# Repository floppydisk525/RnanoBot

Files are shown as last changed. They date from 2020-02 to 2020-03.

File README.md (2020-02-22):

# RnanoBot
This github repository contains the KiCAD files and supporting documents for an Arduino Nano shield containing a TB6612 motor driver chip and LSM9DS1TR 9DOF IMU.  

The TB6612 circuit was influenced from https://github.com/floppydisk525/BoxBotCtrlBrd, which in turn was influenced from https://github.com/BoxBots/control-board.  

The LSM9DS1TR chip was influenced from sparkfun projects such as https://www.sparkfun.com/products/13944 and others.  

The repository name RnanoBot comes from "aRduino NANO roBOT" motor shield with TB6612 &amp; LSM9DS1TR.  

### Datasheets  
Datasheets are in the https://github.com/floppydisk525/RnanoBot/tree/master/board/datasheets folder.  
# Typical Application Notes  
Here are typical application images for key componets.  
## TB6612  
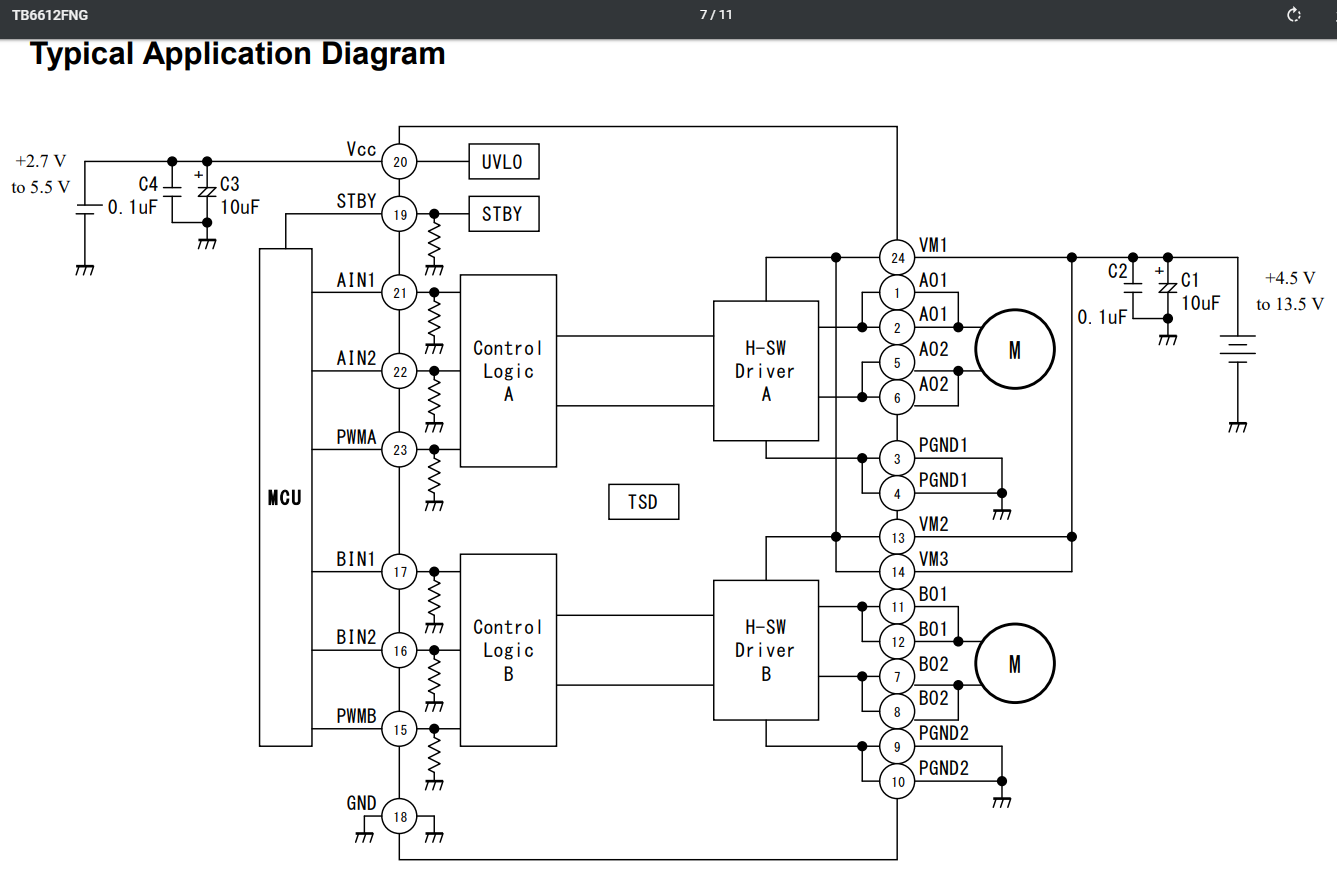
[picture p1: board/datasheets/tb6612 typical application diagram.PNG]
  
## LSM9DS1TR  
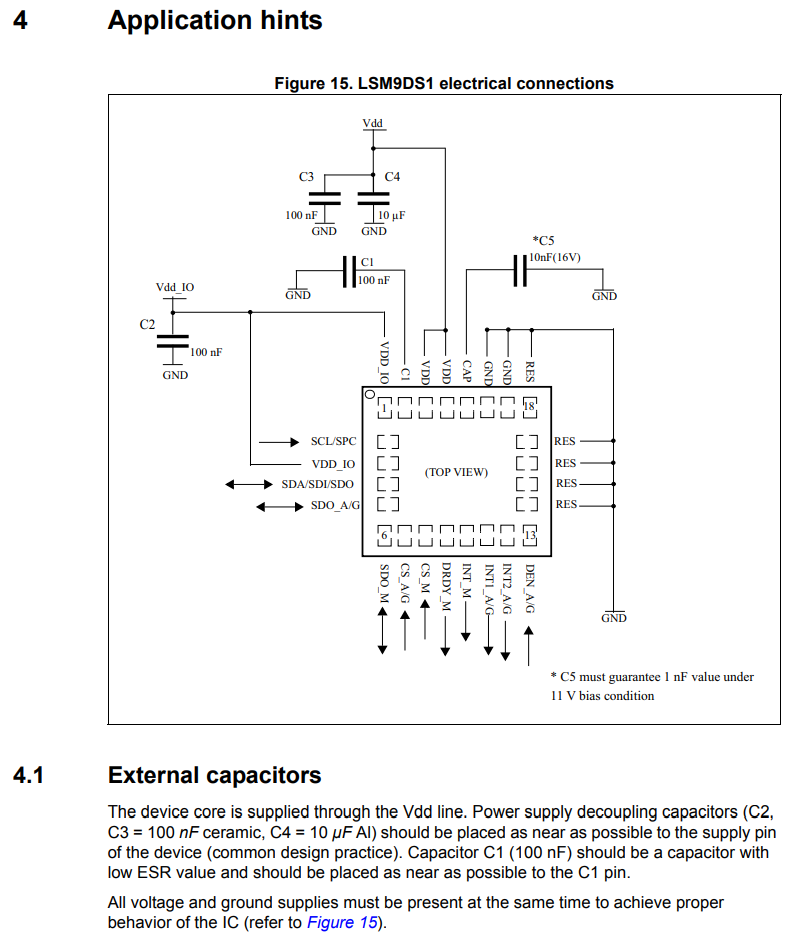
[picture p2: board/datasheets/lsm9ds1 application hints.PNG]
  
The following cut/paste is from:  https://learn.sparkfun.com/tutorials/lsm9ds1-breakout-hookup-guide:  
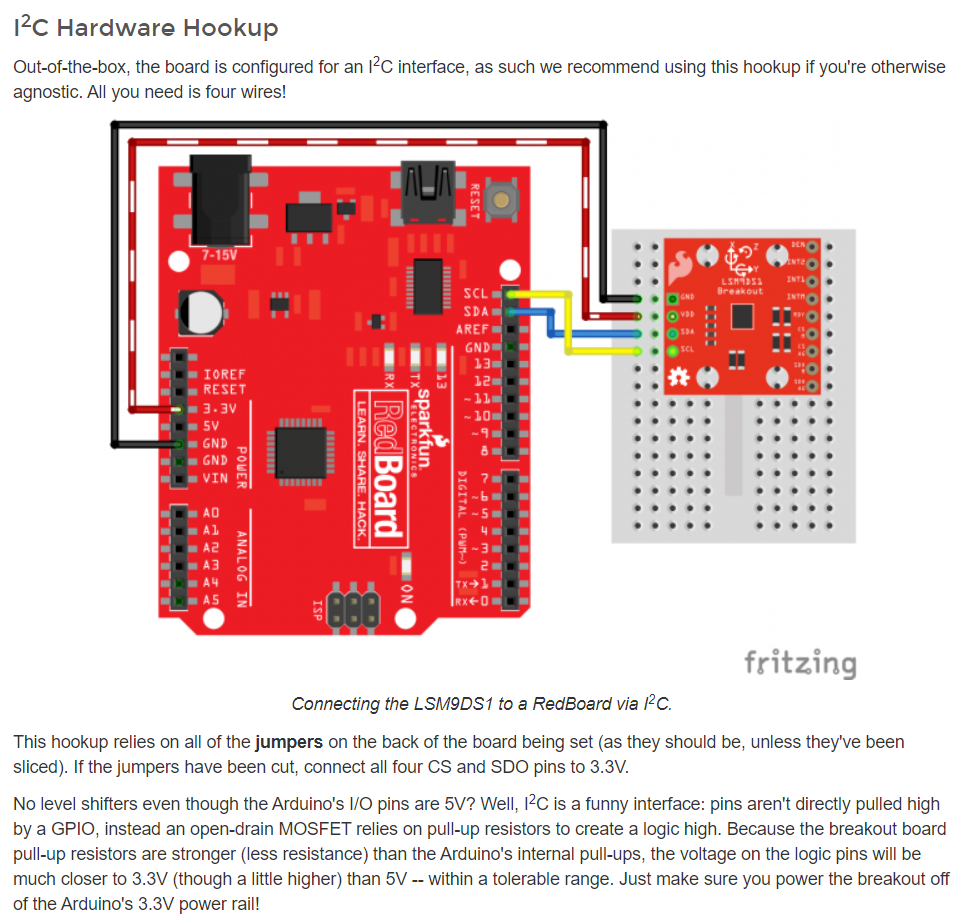
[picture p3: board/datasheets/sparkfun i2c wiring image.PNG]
  

## Arduino NANO Pinout  
I really like this Arduino NANO pinout from Components 101 https://components101.com/microcontrollers/arduino-nano:  
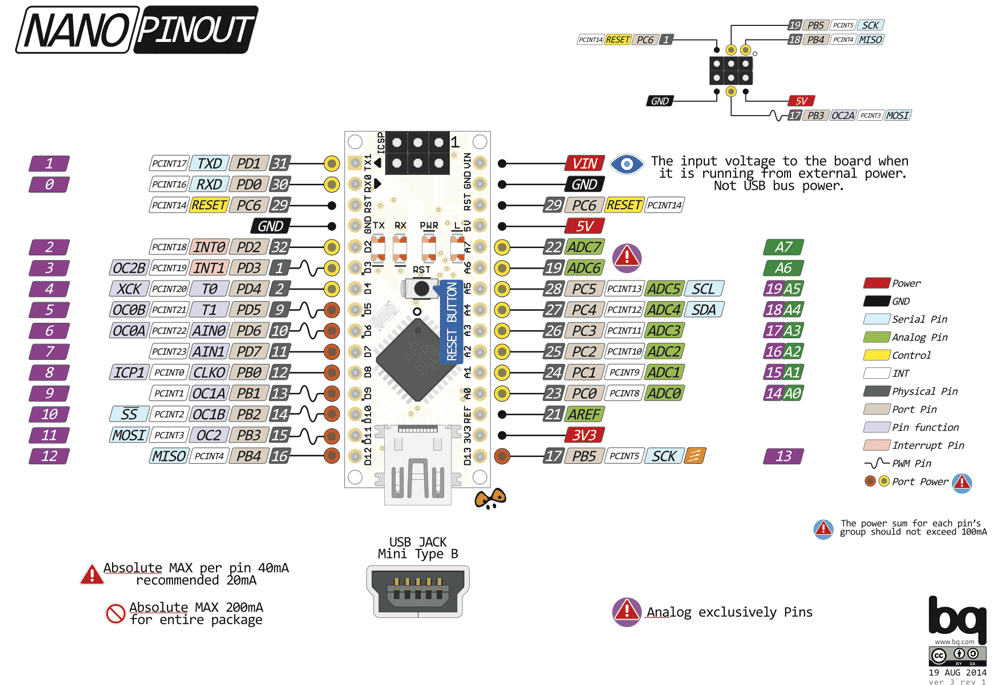
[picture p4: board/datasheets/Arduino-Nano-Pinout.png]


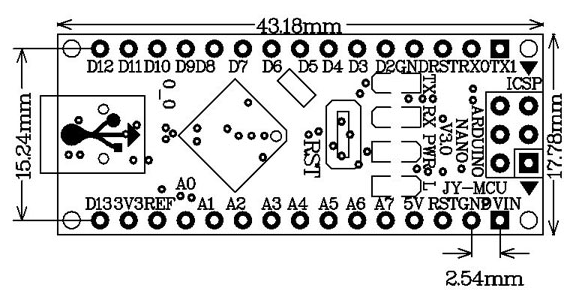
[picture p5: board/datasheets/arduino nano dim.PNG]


### References
https://learn.sparkfun.com/tutorials/lsm9ds1-breakout-hookup-guide  
https://www.sparkfun.com/products/13944  
https://cdn.sparkfun.com/assets/b/0/f/7/4/SparkFun_Motor_Driver-TB6612FNG_v11c.pdf  
https://www.digikey.com/product-detail/en/stmicroelectronics/LSM9DS1TR/497-14946-1-ND/4988079  
https://www.digikey.com/product-detail/en/toshiba-semiconductor-and-storage/TB6612FNGC8EL/TB6612FNGC8ELCT-ND/1730134  
https://components101.com/microcontrollers/arduino-nano  
https://www.youtube.com/watch?v=gGix1oYhTRs  
https://www.st.com/resource/en/datasheet/lsm9ds1.pdf  
http://cheasokchenda.blogspot.com/2018/05/you-can-click-on-link-bellow-to-get-6.html  

[tb6612]:/board/datasheets/tb6612%20typical%20application%20diagram.PNG "TB6612 Typical Application Diagram"
[lsm9ds1]:/board/datasheets/lsm9ds1%20application%20hints.PNG "LSM9DS1TR Application Hint from Datasheet"
[lsm9ds1_spark]:/board/datasheets/sparkfun%20i2c%20wiring%20image.PNG "LSM9DS1TR Spark Fun I2C Wiring example"
[ardnano]:/board/datasheets/Arduino-Nano-Pinout.png "Arduino NANO Pinout from Components 101"
[ard_dim]:/board/datasheets/arduino%20nano%20dim.PNG "Arduino Physical Dimensions"

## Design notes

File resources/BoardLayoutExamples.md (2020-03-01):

# Board Layout Ideas  

The idea is that the board will be a motor shield and accept an arduino Nano.  It is based off the [BoxBotCtrlBrd](https://github.com/floppydisk525/BoxBotCtrlBrd) project and is an improved shield with an ICU added for better control and more capabilities.  

# [BoxBotCtrlBrd](https://github.com/floppydisk525/BoxBotCtrlBrd) Project  
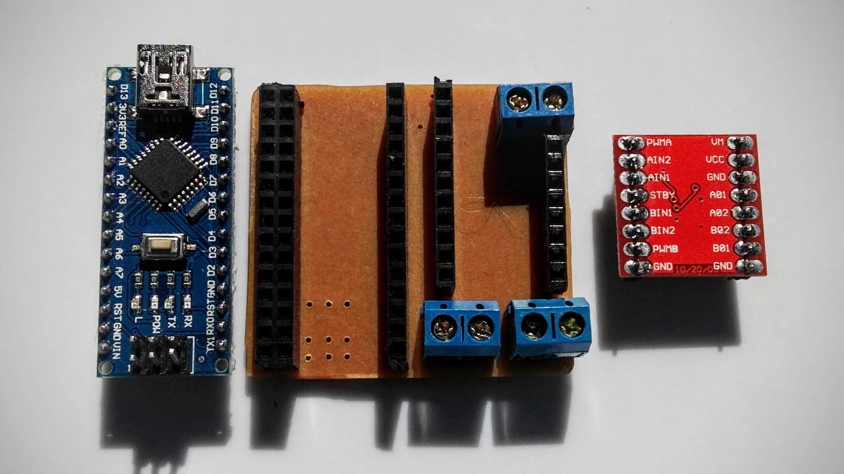
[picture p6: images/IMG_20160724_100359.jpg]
  
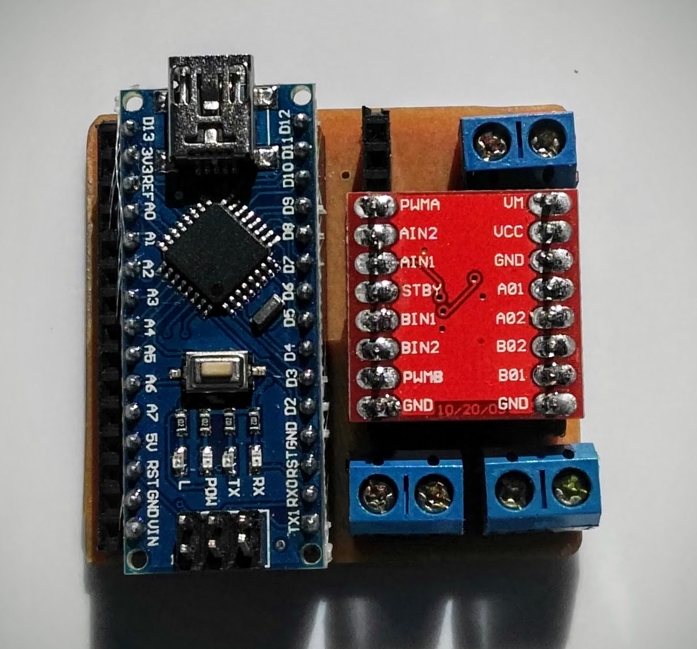
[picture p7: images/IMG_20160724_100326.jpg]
  

# [Rapidonline Example:](https://www.rapidonline.com/arduino-asx00004-mkr-485-rs485-protocol-shield-for-industrial-connections-73-4854)  
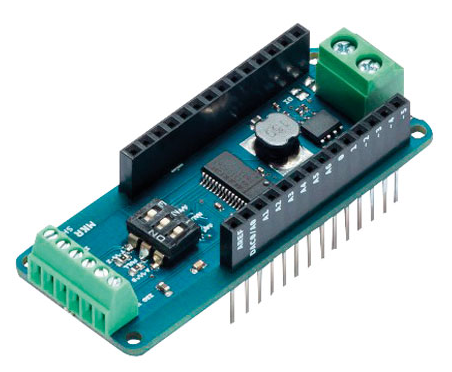
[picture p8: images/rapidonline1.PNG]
  
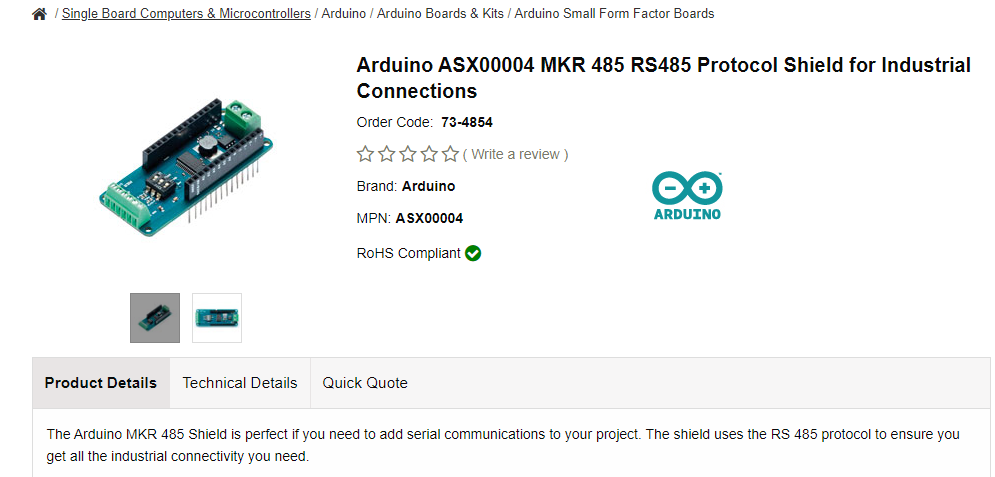
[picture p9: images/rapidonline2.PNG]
  

# [Openhardware IO Shield](https://www.openhardware.io/view/710/Arduino-Nano-NRF24L01-Shield#tabs-comments)  
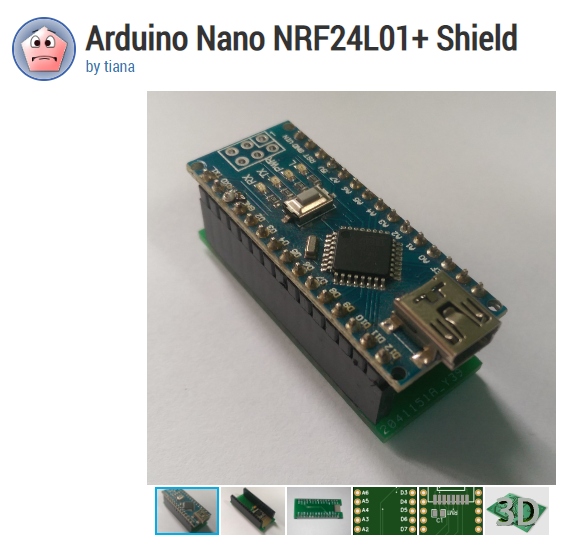
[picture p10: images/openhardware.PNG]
  

# [Freelance Nano Motor Shield Example](https://www.freelancer.com/u/vortexe9000/portfolio/Arduino-Nano-v30-shield-for-small-DC-motors-3527320)  
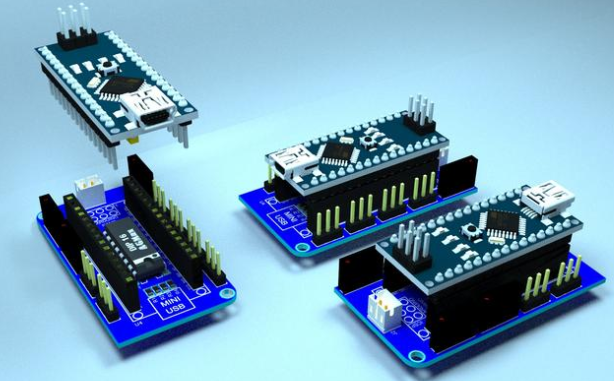
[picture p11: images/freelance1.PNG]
  
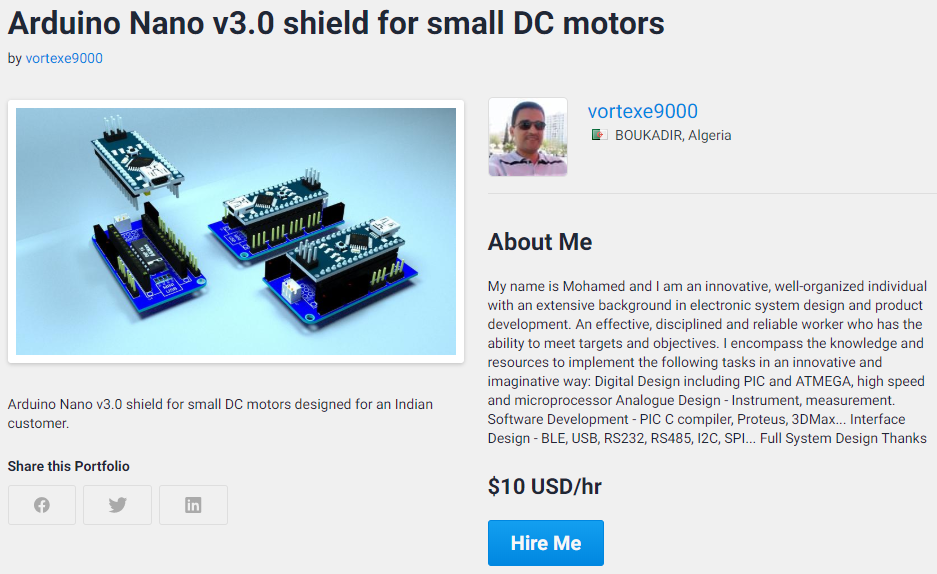
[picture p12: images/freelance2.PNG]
  

# [CE Nano Shield Example](https://shop.controleverything.com/products/arduino-nano-i2c-shield)  
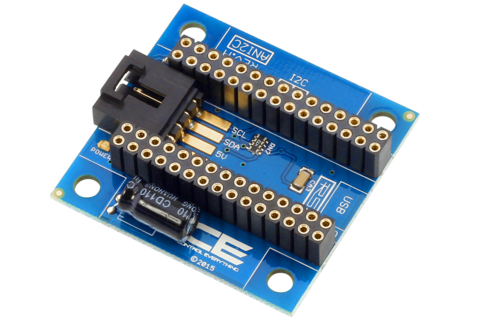
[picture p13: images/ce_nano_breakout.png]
  

# [Gravitech Nano Motor Shield - Nice!](http://www.gravitech.us/2mwfecoadfor.html)  
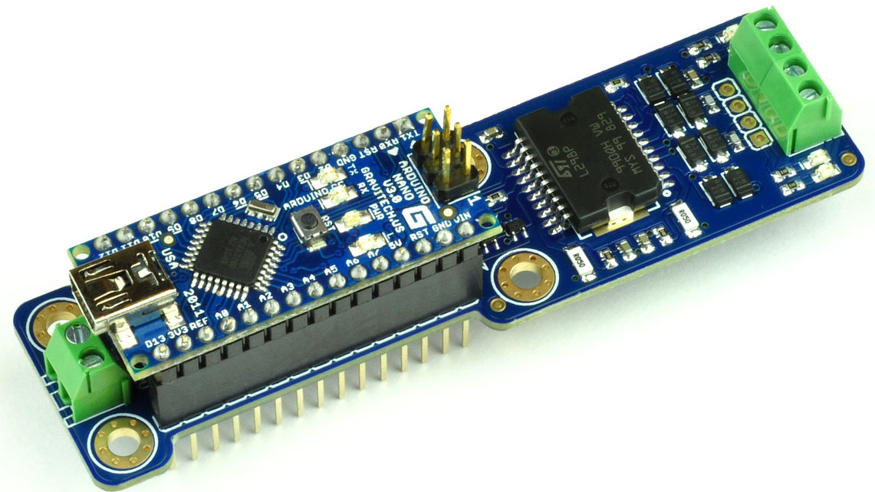
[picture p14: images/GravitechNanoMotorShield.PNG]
 

# RnanoBot - Phoenix Contact Connectors TOO TALL!  
The beauty of KiCAD 3d - look at how tall those phoenix contact connectors are in the 3d view!  TOO TALL!  Going away from them and to basic .1" headers with [CRHO](http://dangerousprototypes.com/blog/2017/06/22/dirty-cables-whats-in-that-pile/) connectors.  Easy, cheap, compact, doable!
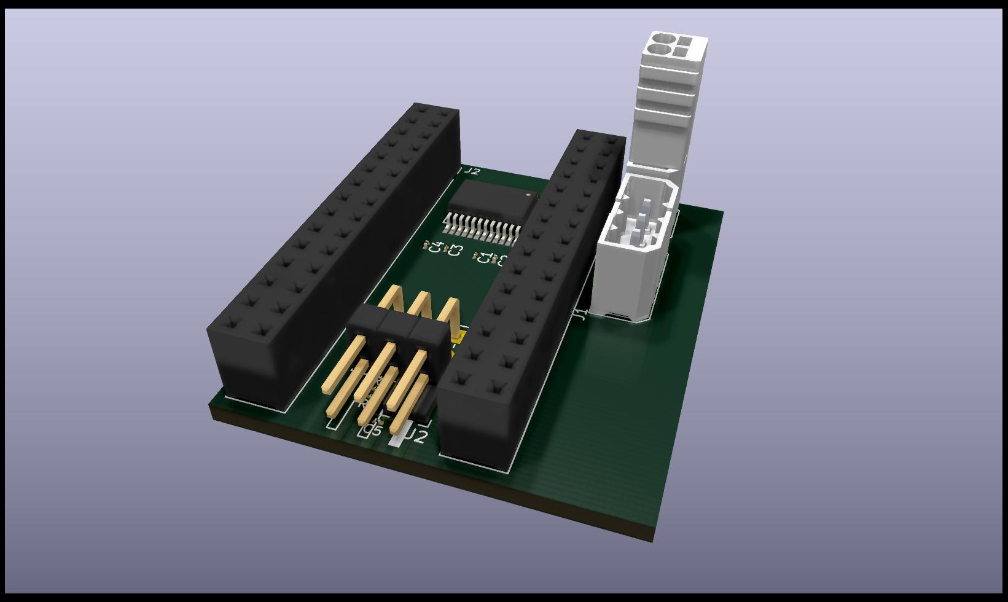
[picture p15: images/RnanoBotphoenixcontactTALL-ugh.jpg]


[rapidonline1]:/images/rapidonline1.PNG "Shield Example"
[rapidonline2]:/images/rapidonline2.PNG "Shield Example"
[openhardware]:/images/openhardware.PNG "Shield Example"
[freelance1]:/images/freelance1.PNG "Shield Example"
[freelance2]:/images/freelance2.PNG "Shield Example"
[boxbot1]:/images/IMG_20160724_100359.jpg "Shield Example"
[boxbot2]:/images/IMG_20160724_100326.jpg "Shield Example"
[ce]:/images/ce_nano_breakout.png "Shield Example"
[gravitech]:/images/GravitechNanoMotorShield.PNG "Shield Example"
[rnano]:/images/RnanoBotphoenixcontactTALL-ugh.jpg "No More Phoenix Contact - too tall!"

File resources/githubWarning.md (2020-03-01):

When I uploaded the files to git, I rec'd these warnings.  Need to check to see if the files will work when downloading?  

## Warning Note from Github
warning: LF will be replaced by CRLF in board/Rnanobot.pretty/pxc_1815264_01_PTSM-0-5-2-HV-2-5-THR-WH-R32_3D.stp.  
The file will have its original line endings in your working directory  
warning: LF will be replaced by CRLF in board/Rnanobot.pretty/pxc_1815280_01_PTSM-0-5-4-HV-2-5-THR-WH-R32_3D.stp.  
The file will have its original line endings in your working directory

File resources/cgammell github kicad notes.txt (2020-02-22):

Chris Gammell's youtube video notes on KiCAD 5.1 and github
https://www.youtube.com/watch?v=gGix1oYhTRs

1. Create new repository on the web.
	Select .gitignore KICAD and MIT License
2. Clone repository on local system.  
	2.1	Copy link to clip board  from github (https://github.com/floppydisk525/RnanoBot.git)
	2.2 git clone https://github.com/floppydisk525/RnanoBot.git
		Note - directory is created in the folder that you issue the command.  So do not 
		create a directory the name of your git project because then the folder will be
		.../documents/somefolder/projfold/projfold  
		Issue the git clone command in the /somefolder/ folder...
3.  Copy files to new direcotry, may need to change KiCAD file names to match folder that the
	files are saved in.

OTHER GITHUB NOTES
Good site for looking better IGNORE code
https://jnavila.github.io/plotkicadsch/

Used this repository as an exmaple for folder structure
https://github.com/John-Nagle/ttyloopdriver

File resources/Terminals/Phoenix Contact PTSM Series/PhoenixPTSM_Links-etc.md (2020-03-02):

# Phoenix Contact links to PTSM Connectors  
https://www.digikey.com/products/en?mpart=1704853&v=277   
https://www.digikey.com/product-detail/en/phoenix-contact/1704857/277-9951-ND/4482512  
https://www.phoenixcontact.com/online/portal/us?uri=pxc-oc-itemdetail:pid=1704857&library=usen&tab=1  
https://www.phoenixcontact.com/online/portal/us?uri=pxc-oc-itemdetail:pid=1704853&library=usen&tab=1  

https://www.digikey.com/product-detail/en/phoenix-contact/1815264/277-9984-1-ND/4696125  
https://www.phoenixcontact.com/online/portal/us?uri=pxc-oc-itemdetail:pid=1815264&library=usen&tab=1  
https://www.digikey.com/product-detail/en/phoenix-contact/1815280/277-9986-1-ND/4696127  
https://www.phoenixcontact.com/online/portal/us?uri=pxc-oc-itemdetail:pid=1815280&library=usen&tab=1  
search  https://www.digikey.com/products/en?mpart=1778696&v=277  

https://www.digikey.com/product-detail/en/phoenix-contact/1814634/277-10062-1-ND/4738858  
https://www.digikey.com/product-detail/en/phoenix-contact/1814647/277-10063-1-ND/4738860  
https://www.phoenixcontact.com/online/portal/us?uri=pxc-oc-itemdetail:pid=1814647&library=usen&tab=1  
  
## Links from RS-Online.  Both Phoenix and RS branded (?) Connectors  
https://au.rs-online.com/web/p/pcb-terminal-blocks/8970998/  
https://au.rs-online.com/web/p/pcb-terminal-blocks/8971082/  
https://au.rs-online.com/web/p/pcb-terminal-blocks/8971001/  
https://au.rs-online.com/web/p/pcb-terminal-blocks/8019822/

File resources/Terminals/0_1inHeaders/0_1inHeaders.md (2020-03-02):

[Mouser right angle headers](https://www.mouser.com/ProductDetail/Harwin/M22-2040305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)  
[Mouser Harwin datasheet link](https://www.mouser.com/datasheet/2/181/M22-204-1134905.pdf)  

[Mouser Connector Harwin M20-1060400](https://www.mouser.com/ProductDetail/Harwin/M20-1060400)  
[Mouser Harwin pins](https://www.mouser.com/ProductDetail/?qs=pYcASEcTDE5O1Aia4WrhLw%3D%3D)  

[PhoenixEnterprises Right Angle Headers](https://www.peconnectors.com/pin-headers-r/a-2x-row-.100/hws5348/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)

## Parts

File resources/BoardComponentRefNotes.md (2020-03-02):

# Misc Parts and Info  

## Farad Values and FootPrint Info  

| Decimal | Farad | Footprint Size |
| --- | --- | --- |
|.000010 | 10 uF |  0603 FootPrint  |
|.0000001 | .1 uF |  0402 FootPrint  |
|.000000010 | 10 nF |  0402 FootPrint  |
|.0000001 | 100 nF|  0402 FootPrint  |

### Links to Capacitors Digikey  
[Digikey .1uF 0402 Capacitors](https://www.digikey.com/product-detail/en/murata-electronics/GRM155R71E104KE14J/490-14603-1-ND/6606209)  
[Digikey 10uF 0603 Capacitors](https://www.digikey.com/product-detail/en/murata-electronics/GRM188R61E106MA73D/490-7202-1-ND/3900486)  

## Resistor Info
Resistors 4.7k 0402 FootPrint  

### Links to Resistor Info  
[Digikey 4.7kOhm 0402 Footprint](https://www.digikey.com/product-detail/en/yageo/RC0402FR-074K7L/311-4.7KLRCT-ND/2827881)  

## Capacitor Placement Notes  
### [How to Place PCB Bypass Capacitors - Optimum Design Blog](http://blog.optimumdesign.com/how-to-place-a-pcb-bypass-capacitor-6-tips)  
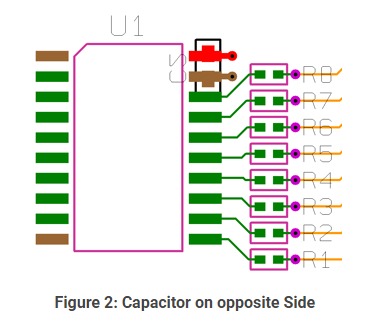
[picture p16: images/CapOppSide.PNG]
  

### [Stack Exchange for Decoupling Cap Placement Question](https://electronics.stackexchange.com/questions/29286/how-important-is-it-to-put-decoupling-caps-on-the-same-side-of-the-pcb)  
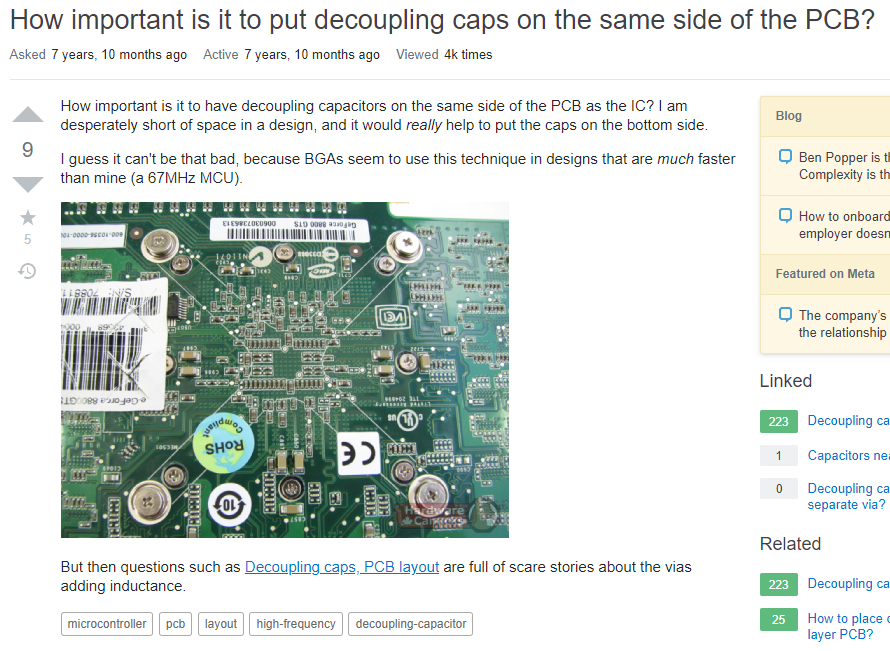
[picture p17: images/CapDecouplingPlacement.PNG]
   

## [Add DIODE 1N4007 to VM (VIN) Input from Electronic-Lab](https://www.electronics-lab.com/project/3-6a-bidirectional-dc-motor-driver-shield-arduino-nano/)  
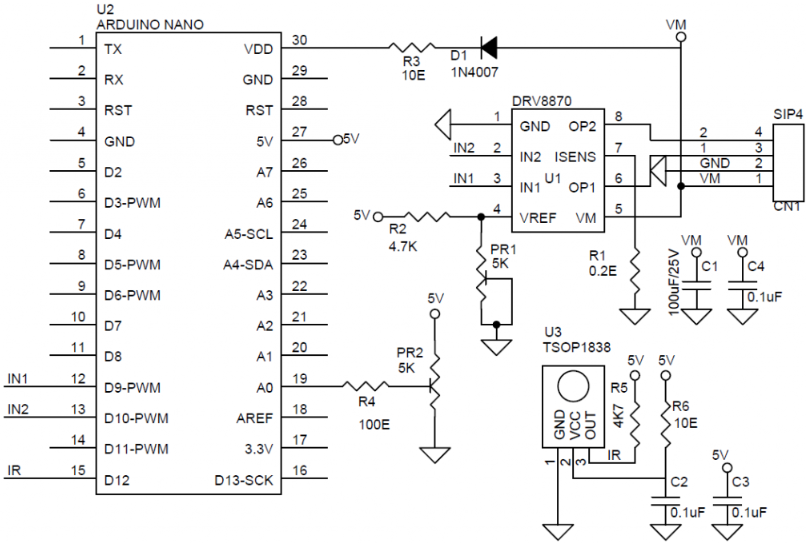
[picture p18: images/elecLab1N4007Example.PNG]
 

## [PCB Board SMD (SMT) Relative Sizes](https://electronics.stackexchange.com/questions/375637/difference-between-1206-0805-and-0603-smd-resistor)  
[Wikipedia Surface-mount_technology](https://en.wikipedia.org/wiki/Surface-mount_technology#Rectangular_passive_components)  
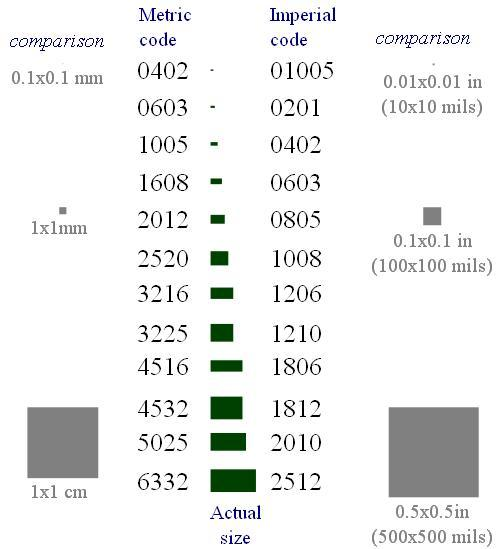
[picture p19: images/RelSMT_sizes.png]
   

## [CRHO 0.1" Connectors - the basic connector!](http://dangerousprototypes.com/blog/2017/06/22/dirty-cables-whats-in-that-pile/) 
Rather than using the Phoenix Contact connectors (too tall), switch to using the basic CRHO connectors.  The link from [Dangerous Prototypes](http://dangerousprototypes.com/blog/2017/06/22/dirty-cables-whats-in-that-pile/) is excellent and they have a link to Dirty PCBs, which is a good resource (I've heard) for PCB fab AND Cable Fab.
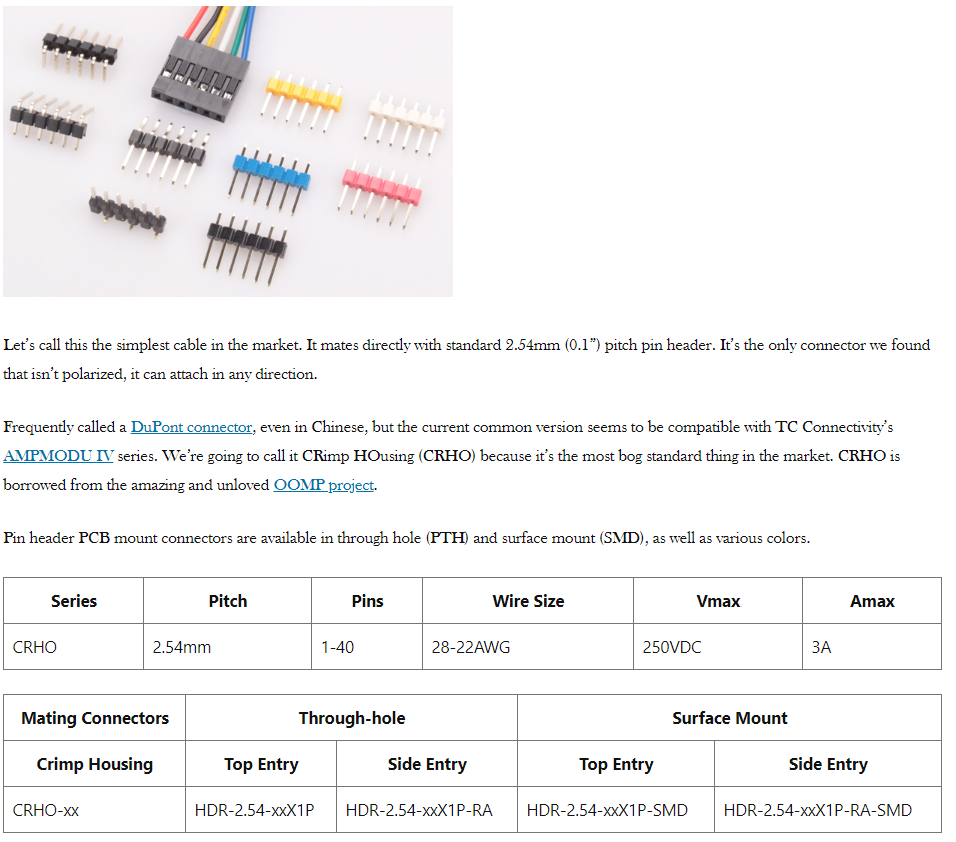
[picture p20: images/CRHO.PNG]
  

[cap1]:/images/CapOppSide.PNG "Cap Placement Example"
[cap2]:/images/CapDecouplingPlacement.PNG "Cap Placement Example"
[elab]:/images/elecLab1N4007Example.PNG "DIODE Example"
[smtsizes]:/images/RelSMT_sizes.png "SMT Sizes"
[chro]:/images/CRHO.PNG "CRHO Connectors"

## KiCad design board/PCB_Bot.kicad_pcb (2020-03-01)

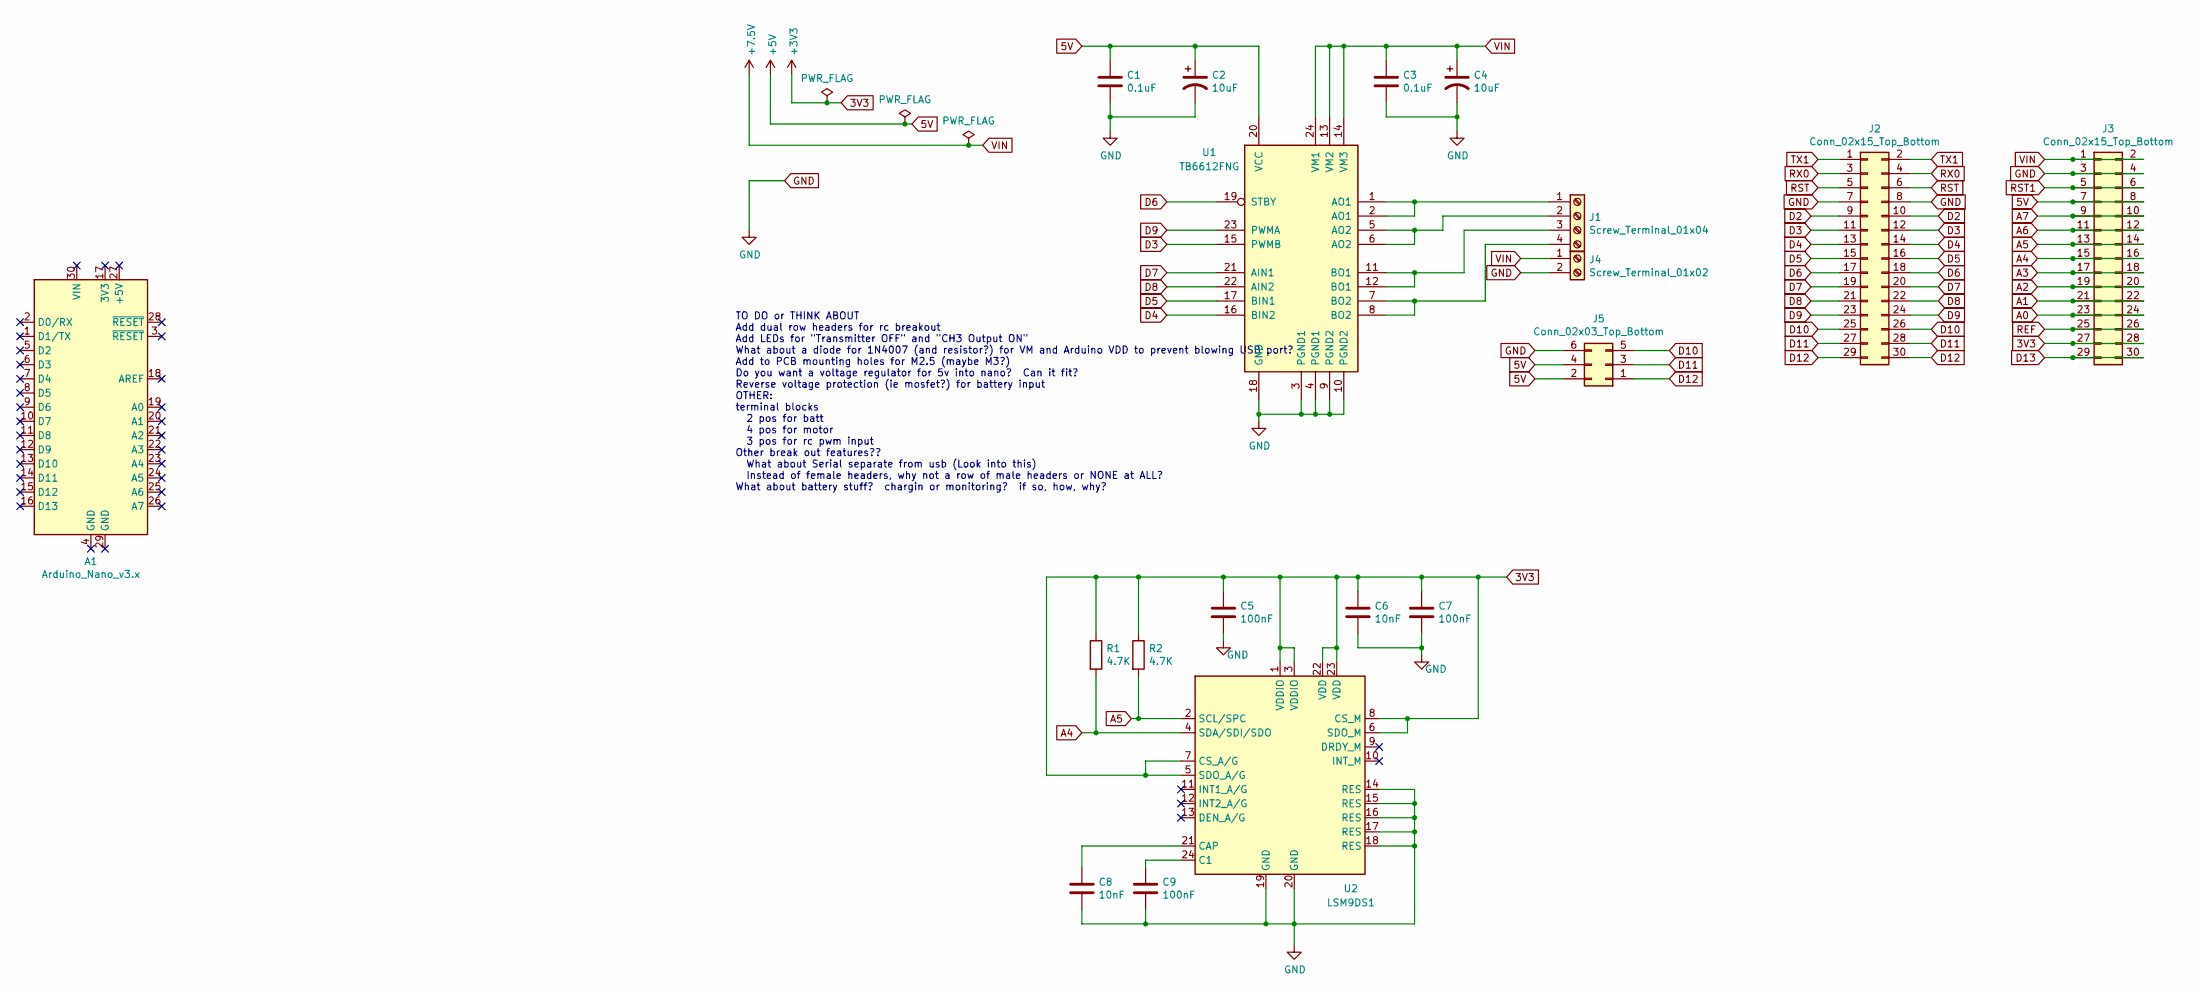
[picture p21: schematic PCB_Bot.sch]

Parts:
A1: Arduino_Nano_v3.x; Arduino_Nano
C1, C3: 0.1uF; C_01005_0402Metric
C2, C4: 10uF; C_0201_0603Metric
C5, C7, C9: 100nF; C_01005_0402Metric
C6, C8: 10nF; C_0201_0603Metric
J1: Screw_Terminal_01x04; PTSM_Phoenix_Contact_4-pos_Base_Strip_1815280
J2, J3: Conn_02x15_Top_Bottom; PinSocket_2x15_P2.54mm_Vertical
J4: Screw_Terminal_01x02; PTSM_Phoenix_Contact_2-pos_Base_Strip_1815264
J5: Conn_02x03_Top_Bottom; PinHeader_2x03_P2.54mm_Horizontal
R1, R2: 4.7K; R_01005_0402Metric
U1: TB6612FNG; SSOP-24_5.3x8.2mm_P0.65mm
U2: LSM9DS1; LGA-24L_3x3.5mm_P0.43mm

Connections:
3V3: C5.1, C6.1, C7.1, J3.27, J3.28, R1.1, R2.1, U2.1 (VDDIO), U2.3 (VDDIO), U2.5 (SDO_A/G), U2.6 (SDO_M), U2.7 (CS_A/G), U2.8 (CS_M), U2.22 (VDD), U2.23 (VDD)
5V: C1.1, C2.1, J3.7, J3.8, J5.2, J5.4, U1.20 (VCC)
A0: J3.23, J3.24
A1: J3.21, J3.22
A2: J3.19, J3.20
A3: J3.17, J3.18
A4: J3.15, J3.16, R1.2, U2.4 (SDA/SDI/SDO)
A5: J3.13, J3.14, R2.2, U2.2 (SCL/SPC)
A6: J3.11, J3.12
A7: J3.9, J3.10
D2: J2.9, J2.10
D3: J2.11, J2.12, U1.15 (PWMB)
D4: J2.13, J2.14, U1.16 (BIN2)
D5: J2.15, J2.16, U1.17 (BIN1)
D6: J2.17, J2.18, U1.19 (STBY)
D7: J2.19, J2.20, U1.21 (AIN1)
D8: J2.21, J2.22, U1.22 (AIN2)
D9: J2.23, J2.24, U1.23 (PWMA)
D10: J2.25, J2.26, J5.5
D11: J2.27, J2.28, J5.3
D12: J2.29, J2.30, J5.1
D13: J3.29, J3.30
GND: C1.2, C2.2, C3.2, C4.2, C5.2, C6.2, C7.2, C8.2, C9.2, J2.7, J2.8, J3.3, J3.4, J4.2, J5.6, U1.3 (PGND1), U1.4 (PGND1), U1.9 (PGND2), U1.10 (PGND2), U1.18 (GND), U2.14 (RES), U2.15 (RES), U2.16 (RES), U2.17 (RES), U2.18 (RES), U2.19 (GND), U2.20 (GND)
unnamed: C8.1, U2.21 (CAP)
unnamed: C9.1, U2.24 (C1)
unnamed: J1.1, U1.1 (AO1), U1.2 (AO1)
unnamed: J1.2, U1.5 (AO2), U1.6 (AO2)
unnamed: J1.3, U1.11 (BO1), U1.12 (BO1)
unnamed: J1.4, U1.7 (BO2), U1.8 (BO2)
REF: J3.25, J3.26
RST: J2.5, J2.6
RST1: J3.5, J3.6
RX0: J2.3, J2.4
TX1: J2.1, J2.2
VIN: C3.1, C4.1, J3.1, J3.2, J4.1, U1.13 (VM2), U1.14 (VM3), U1.24 (VM1)

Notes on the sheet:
TO DO or THINK ABOUT Add dual row headers for rc breakout Add LEDs for "Transmitter OFF" and "CH3 Output ON" What about a diode for 1N4007 (and resistor?) for VM and Arduino VDD to prevent blowing USB port? Add to PCB mounting holes for M2.5 (maybe M3?) Do you want a voltage regulator for 5v into n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

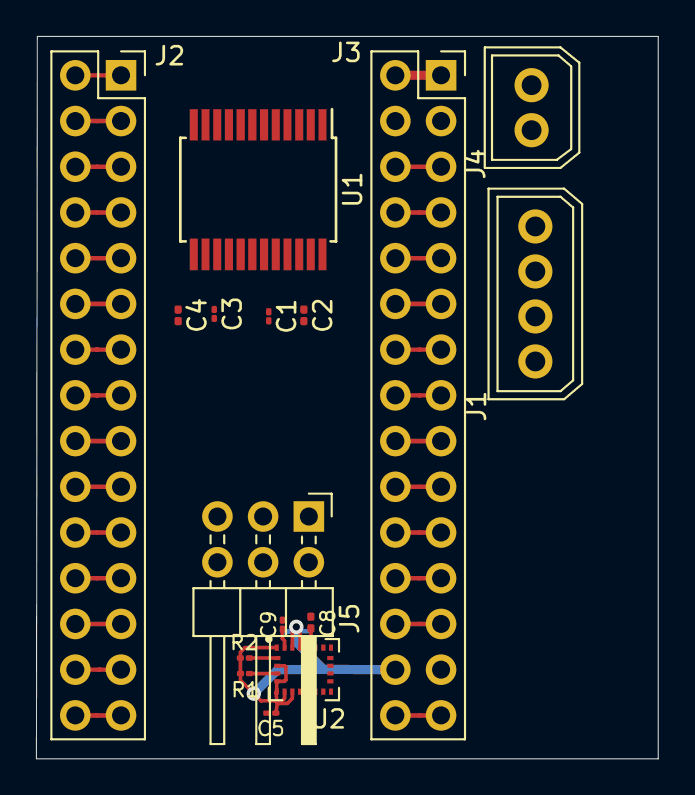
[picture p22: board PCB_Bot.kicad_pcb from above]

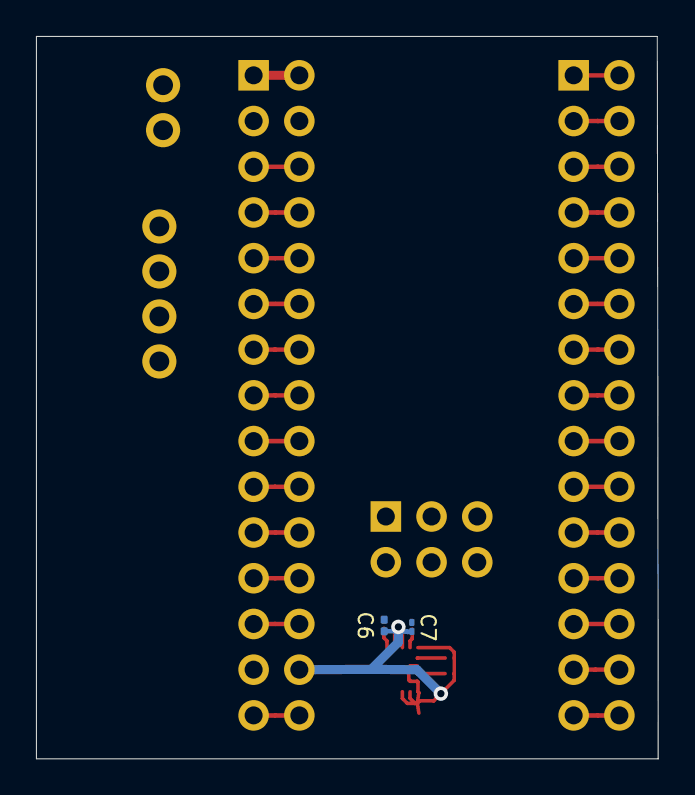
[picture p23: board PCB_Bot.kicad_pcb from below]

Board: 2 copper layers, 34.5 x 40.1 mm, 18 parts (2 on the bottom side), 35 nets.

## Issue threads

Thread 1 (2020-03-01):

Will step files work when downloaded to new machine w/ CRLF vs LF?

floppydisk525, 2020-03-01:
When I uploaded the files to git, I rec'd these warnings. Need to check to see if the files will work when downloading?

Warning Note from Github
warning: LF will be replaced by CRLF in board/Rnanobot.pretty/pxc_1815264_01_PTSM-0-5-2-HV-2-5-THR-WH-R32_3D.stp.
The file will have its original line endings in your working directory
warning: LF will be replaced by CRLF in board/Rnanobot.pretty/pxc_1815280_01_PTSM-0-5-4-HV-2-5-THR-WH-R32_3D.stp.
The file will have its original line endings in your working directory

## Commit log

2020-02-22 initial commit of KiCADproject and folder structure setup
    [PCB_Bot.kicad_pcb, PCB_Bot.sch]
2020-02-22 add componenets 101 arduino NANA image to readme.md
2020-02-22 update schematic, add 9Dof pdf
    [PCB_Bot.sch]
2020-02-22 add dims of arduino nano and link in readme.md
2020-02-23 add screw terminal to breakout motors and battery input power
    [PCB_Bot.sch]
2020-02-23 add farad values and update schematic
    [PCB_Bot.sch]
2020-02-23 update pcbnew board layout and update foot prints
    [PCB_Bot.kicad_pcb, PCB_Bot.sch]
2020-02-23 boardlayoutexamples.md file uploaded with links and images to fill out file
2020-02-23 update boardlayoutexmaple md
2020-02-23 add box bot images for boardlayoutexmaple.md
2020-02-23 add bold to links in boardlayoutexmaple.md
2020-02-23 more bold to links in boardlayoutexmaple.md
2020-02-23 add ce images to boardlayoutexmxaple.md
2020-02-24 Change connectors in schematic and in pcbnew. add some tracks in pcbnew
    [PCB_Bot.kicad_pcb, PCB_Bot.sch]
2020-02-24 update notes in schematic to better align w/ todo list
    [PCB_Bot.sch]
2020-02-24 update notes in schematic
    [PCB_Bot.sch]
2020-02-25 change screw terminals from 1 to 2, add another for RC input
    [PCB_Bot.kicad_pcb, PCB_Bot.sch]
2020-02-25 pcbnew move capacitors and resistors around
    [PCB_Bot.kicad_pcb]
2020-02-25 minor schematic changes, upload and turn off.
    [PCB_Bot.sch]
2020-02-26 update pcbnew orienatation
    [PCB_Bot.kicad_pcb, PCB_Bot.sch]
2020-02-27 update pcbnew, add new track widths
    [PCB_Bot.kicad_pcb]
2020-03-01 update pcbnew and add some tracks - that can be replaced at some point...
    [PCB_Bot.kicad_pcb, PCB_Bot.sch]
2020-03-01 look at layout of nano, add notes_examples to md files
    [PCB_Bot.kicad_pcb, PCB_Bot.sch]
2020-03-01 typo in board resources md
2020-03-01 fix md file formatting boardcomponentrefntoes.md
2020-03-01 add smt sizes to board...md
2020-03-01 update power flags in schematic, check erros and warnings - all warnings now
    [PCB_Bot.sch]
2020-03-01 add step files for phoenix contact 2.5mm terminal blocks and update in model.
    [PCB_Bot.kicad_pcb]
2020-03-01 add stp files and update boardlayoutex.md
    [PCB_Bot.kicad_pcb]
2020-03-01 typo fix in boardlayoutex.md
2020-03-01 add chro connectors to boardrefnotes
